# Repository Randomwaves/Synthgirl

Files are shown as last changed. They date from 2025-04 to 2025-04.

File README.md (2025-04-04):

# Synthgirl

Welcome to the official GitHub repository for **Synthgirl** by [Randomwaves](https://randomwaves.io).  
Here you'll find everything you need to explore, modify, or build your own Synthgirl— from firmware to circuit design.

## 📁 Repository Structure

- **hardware/**  
  Schematics, PCB design files, and everything related to the physical build of Synthgirl.

- **software/**  
  Source code for the Synthgirl firmware, libraries, and tools.

## 🛠️ For Developers & Hackers

Whether you're here to flash custom firmware or fork the design, we've made the files open and accessible. Contributions, forks, and pull requests are always welcome.

## 📄 License

All contents of this repository are licensed under the [MIT License](LICENSE).

---

Made with ❤️ by Randomwaves.

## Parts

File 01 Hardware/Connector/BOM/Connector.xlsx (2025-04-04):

Connector
Qty | Value | Device | Package | Parts | Description
1 |  | M20-7910642R | M20-7910642R | JP1
1 | HFW6R-6STE1H1LF | HFW6R-6STE1H1LF | HFW6R-6STE1H1LF | U$1

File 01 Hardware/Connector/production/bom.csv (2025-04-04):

Designator | Footprint | Quantity | Value | LCSC Part #
JP1 | 1X06-SMD-FEMALE-V2 | 1 | M06SMD-FEMALE-V2
U$1 | HFW6R-2STE1LF | 1 | HFW6R-2STE1LF

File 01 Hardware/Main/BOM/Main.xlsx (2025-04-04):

Main
Qty | Value | Device | Package | Parts | Description | ARROW_PART_NUMBER | ARROW_PRICE-STOCK | DESCRIPTION | HEIGHT | MANUFACTURER_NAME | MANUFACTURER_PART_NUMBER | MOUSER_PART_NUMBER | MOUSER_PRICE-STOCK | PROD_ID | VALUE
1 | 68712014022 | 68712014022 | 68712014022 | J4 | Wurth Elektronik 687 Series 0.5mm 20 Way 1 Row Straight PCB Socket Surface Mount Wire to Board |  |  | Wurth Elektronik 687 Series 0.5mm 20 Way 1 Row Straight PCB Socket Surface Mount Wire to Board | 2.1mm | Wurth Elektronik | 68712014022 | 710-68712014022 | https://www.mouser.co.uk/ProductDetail/Wurth-Elektronik/68712014022?qs=ZtY9WdtwX57%2F0bEhtjzEjA%3D%3D
1 | 150060RS75000 | 150060RS75000 | LEDC1608X80N | LED1 | WURTH ELEKTRONIK - 150060RS75000 - LED, 0603, RED, 250MCD, 625NM |  |  | WURTH ELEKTRONIK - 150060RS75000 - LED, 0603, RED, 250MCD, 625NM | 0.8mm | Wurth Elektronik | 150060RS75000 | 710-150060RS75000 | https://www.mouser.co.uk/ProductDetail/Wurth-Elektronik/150060RS75000?qs=LlUlMxKIyB3QnmZ3fw%2FVCA%3D%3D
1 | 150060VS75000 | 150060VS75000 | LEDC1608X80N | LED3 | 2.4 V Green LED 1608 (0603) SMD, Wurth Elektronik WL-SMCW 150060VS75000 |  |  | 2.4 V Green LED 1608 (0603) SMD, Wurth Elektronik WL-SMCW 150060VS75000 | 0.8mm | Wurth Elektronik | 150060VS75000 | 710-150060VS75000 | https://www.mouser.co.uk/ProductDetail/Wurth-Elektronik/150060VS75000?qs=LlUlMxKIyB1Q1Bi5mQ%2FKLw%3D%3D
1 | 150060YS75000 | 150060YS75000 | LEDC1608X80N | LED2 | LED,Wurth Elektronik,150060YS75000 Wurth Elektronik 150060YS75000, WL-SMCW Series Yellow LED, 590 nm, 1608 (0603) Clear, Rectangle Lens SMD Package |  |  | LED,Wurth Elektronik,150060YS75000 Wurth Elektronik 150060YS75000, WL-SMCW Series Yellow LED, 590 nm, 1608 (0603) Clear, Rectangle Lens SMD Package | 0.8mm | Wurth Elektronik | 150060YS75000 | 710-150060YS75000 | https://www.mouser.co.uk/ProductDetail/Wurth-Elektronik/150060YS75000?qs=LlUlMxKIyB0nKmwefHgtZw%3D%3D
1 | 216990-0001 | 216990-0001 | 2169900001 | USB1 | MOLEX - 216990-0001 - USB Connector, USB Type C, USB 2.0, Receptacle, 16 Ways, Surface Mount, Right Angle{0000} |  |  | MOLEX - 216990-0001 - USB Connector, USB Type C, USB 2.0, Receptacle, 16 Ways, Surface Mount, Right Angle{0000} | 3.36mm | Molex | 216990-0001 | 538-216990-0001 | https://www.mouser.co.uk/ProductDetail/Molex/216990-0001?qs=DRkmTr78QAS%252B9wQ3YlpV3Q%3D%3D
1 | 68715014022 | 68715014022 | 68715014022 | J1 | Connector 0.5mm, FFC/FPC, SMT,r/a,50w,FFC/FPC SMT Series 0.5mm Pitch 50 Way Right Angle SMT Female FPC Connector, ZIF Top Contact |  |  | Connector 0.5mm, FFC/FPC, SMT,r/a,50w,FFC/FPC SMT Series 0.5mm Pitch 50 Way Right Angle SMT Female FPC Connector, ZIF Top Contact | 2mm | Wurth Elektronik
1 | ABM7-8.000MHZ-D2Y-T | ABM7-8.000MHZ-D2Y-T | ABM78000MHZD2YT | Y1 | ABRACON - ABM7-8.000MHZ-D2Y-T - CRYSTAL, 8MHZ, 18PF, SMD | ABM7-8.000MHZ-D2Y-T | https://www.arrow.com/en/products/abm7-8.000mhz-d2y-t/abracon | ABRACON - ABM7-8.000MHZ-D2Y-T - CRYSTAL, 8MHZ, 18PF, SMD | 1.4mm | ABRACON | ABM7-8.000MHZ-D2Y-T | 815-ABM7-8-D2Y-T | https://www.mouser.co.uk/ProductDetail/ABRACON/ABM7-8000MHZ-D2Y-T?qs=LoTOQoUkC8SFsmY8snleBA%3D%3D
1 | AP7365-18WG-7 | AP7365-18WG-7 | SOT95P285X130-5N | IC6 | DiodesZetex AP7365-18WG-7, LDO Voltage Regulator, 600mA, 1.8 V +/-2%, 2 6 Vin, 5-Pin SOT-25 | AP7365-33WG-7 | https://www.arrow.com/en/products/ap7365-33wg-7/diodes-incorporated | DiodesZetex AP7365-33WG-7, LDO Voltage Regulator, 600mA, 3.3 V +/-2%, 2 6 Vin, 5-Pin SOT-25 | 1.3mm | Diodes Inc. | AP7365-33WG-7 | 621-AP7365-33WG-7 | https://www.mouser.co.uk/ProductDetail/Diodes-Incorporated/AP7365-33WG-7?qs=abZ1nkZpTuOZFvxvoFPL0w%3D%3D
2 | AP7365-33WG-7 | AP7365-33WG-7 | SOT95P285X130-5N | IC5, IC7 | DiodesZetex AP7365-33WG-7, LDO Voltage Regulator, 600mA, 3.3 V +/-2%, 2 6 Vin, 5-Pin SOT-25 | AP7365-33WG-7 | https://www.arrow.com/en/products/ap7365-33wg-7/diodes-incorporated | DiodesZetex AP7365-33WG-7, LDO Voltage Regulator, 600mA, 3.3 V +/-2%, 2 6 Vin, 5-Pin SOT-25 | 1.3mm | Diodes Inc. | AP7365-33WG-7 | 621-AP7365-33WG-7 | https://www.mouser.co.uk/ProductDetail/Diodes-Incorporated/AP7365-33WG-7?qs=abZ1nkZpTuOZFvxvoFPL0w%3D%3D
32 | 0.1uF | CAP-0603 | CAP-0603 | C1, C2, C3, C4, C5, C6, C7, C9, C11, C12, C13, C14, C15, C21, C24, C25, C26, C27, C28, C29, C30, C31, C33, C34, C35, C36, C38, C39, C41, C43, C45, C46
1 | 10uF | CAP-0603 | CAP-0603 | C19
2 | 1uF | CAP-0603 | CAP-0603 | C20, C22
6 | 2.2uF | CAP-0603 | CAP-0603 | C17, C18, C37, C40, C42, C44
2 | 33pF | CAP-0603 | CAP-0603 | C8, C10
4 | 4.7uF | CAP-0603 | CAP-0603 | C16, C23, C32, C47
2 | 10uF | CAP-POL-1206 | CAP-POL-1206 | CP1, CP2
1 | 1N4148 | DIODESOD-323 | SOD-323 | D2 | Diode
1 | H11L1SM | H11L1SM | SMT-6PIN-(LEAD-BEND) | IC8 | 6-Pin DIP Schmitt Trigger Output Optocoupler |  |  | 6-Pin DIP Schmitt Trigger Output Optocoupler | mm | onsemi | H11L1SM | 512-H11L1SM | https://www.mouser.co.uk/ProductDetail/onsemi-Fairchild/H11L1SM?qs=9h%252BT%2FFFCxR8rbqOmNiGmNQ%3D%3D
1 | HFW6R-1STE1LF | HFW6R-1STE1LF | HFW6R-1STE1LF | J7
1 | IS42S16800F-7TLI | IS42S16800F-7TLI | SOP80P1176X120-54N | IC3 | DRAM 128M, 3.3V, SDRAM, 8Mx16, 143Mhz, 54 pin TSOP II (400 mil) RoHS, IT | IS42S16800F-7TLI | https://www.arrow.com/en/products/is42s16800f-7tli/integrated-silicon-solution-inc | DRAM 128M, 3.3V, SDRAM, 8Mx16, 143Mhz, 54 pin TSOP II (400 mil) RoHS, IT | 1.2mm | Integrated Silicon Solution Inc. | IS42S16800F-7TLI | 870-IS42S16800F-7TLI | https://www.mouser.co.uk/ProductDetail/ISSI/IS42S16800F-7TLI?qs=DfG0HhEx1UWqxa76yijZ5Q%3D%3D
1 | L-KLS1-TF-003-H1.85-R | L-KLS1-TF-003-H1.85-R | L-KLS1-TF-003-H1.85-R | J2 | Micro SD Card Connector |  |  | Micro SD Card Connector | mm | KLS Electronic | L-KLS1-TF-003-H1.85-R
1 | MBR0520LT3G | MBR0520LT3G | SOD3716X135N | D1 | ON SEMICONDUCTOR - MBR0520LT3G - RECTIFIER, SCHOTTKY, 0.5A, 20V, SOD-123 | MBR0520LT3G | https://www.arrow.com/en/products/mbr0520lt3g/on-semiconductor | ON SEMICONDUCTOR - MBR0520LT3G - RECTIFIER, SCHOTTKY, 0.5A, 20V, SOD-123 | 1.35mm | ON Semiconductor | MBR0520LT3G | 863-MBR0520LT3G | https://www.mouser.co.uk/ProductDetail/ON-Semiconductor/MBR0520LT3G?qs=3JMERSakebrHITezQJBmeQ%3D%3D
1 | MP3302DJ-LF-Z | MP3302DJ-LF-Z | SOT95P280X100-5N | IC2 | LED Lighting Drivers 1.3A, 1.3MHz WLED Driver |  |  | LED Lighting Drivers 1.3A, 1.3MHz WLED Driver | 1mm | Monolithic Power Systems (MPS) | MP3302DJ-LF-Z | 946-MP3302DJLFZ | https://www.mouser.co.uk/ProductDetail/Monolithic-Power-Systems-MPS/MP3302DJ-LF-Z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
1 | NRS5024T4R7MMGJ | NRS5024T4R7MMGJ | NRS5024T4R7MMGJ | L1 | Inductor Power Shielded Wirewound 4.7uH 20% 100KHz Ferrite 2A 0.066Ohm DCR T/R | NRS5024T4R7MMGJ | https://www.arrow.com/en/products/nrs5024t4r7mmgj/taiyo-yuden | Inductor Power Shielded Wirewound 4.7uH 20% 100KHz Ferrite 2A 0.066Ohm DCR T/R | 2.4mm | TAIYO YUDEN | NRS5024T4R7MMGJ | 963-NRS5024T4R7MMGJ | https://www.mouser.co.uk/ProductDetail/Taiyo-Yuden/NRS5024T4R7MMGJ?qs=vF%252B8ahGVilffmVxWIbH5HQ%3D%3D
4 | 0 | RES-0603 | RES-0603 | R20, R21, R25, R26
2 | 10 | RES-0603 | RES-0603 | R8, R11
1 | 100 | RES-0603 | RES-0603 | R22
1 | 100K | RES-0603 | RES-0603 | R10
5 | 10K | RES-0603 | RES-0603 | R2, R3, R4, R9, R23
2 | 2.2K | RES-0603 | RES-0603 | R18, R19
6 | 220 | RES-0603 | RES-0603 | R1, R5, R6, R7, R15, R28
2 | 47 | RES-0603 | RES-0603 | R24, R27
1 | 470 | RES-0603 | RES-0603 | R29
5 | 47K | RES-0603 | RES-0603 | R12, R13, R14, R16, R17
3 | 600 | BLM18AG601SN1D | BLM18AG601SN1D | FB01, FB02, FB03
1 | SGTL5000XNAA3 | SGTL5000XNAA3 | QFN50P500X500X90-33N | IC4 | NXP, Audio Codec Stereo Audio 2-channel 24bit- 96kHz Serial-I2C, Serial-SPI 32-Pin QFN | SGTL5000XNAA3 | https://www.arrow.com/en/products/sgtl5000xnaa3/nxp-semiconductors | NXP, Audio Codec Stereo Audio 2-channel 24bit- 96kHz Serial-I2C, Serial-SPI 32-Pin QFN | 0.9mm | NXP | SGTL5000XNAA3 | 841-SGTL5000XNAA3 | https://www.mouser.co.uk/ProductDetail/NXP-Semiconductors/SGTL5000XNAA3?qs=g5o6z0NmdpQ52bnp6yi7dA%3D%3D
5 | SJ-3503-SMT-TR | SJ-3503-SMT-TR | SJ3503SMTTR | J3, J5, J6, J8, J9 | CONN JACK STEREO 3.5MM SMD R/A | SJ-3503-SMT-TR | https://www.arrow.com/en/products/sj-3503-smt-tr/cui-devices?region=nac | CONN JACK STEREO 3.5MM SMD R/A | 5.8mm | CUI Inc. | SJ-3503-SMT-TR | 490-SJ-3503-SMT-TR | https://www.mouser.co.uk/ProductDetail/CUI-Devices/SJ-3503-SMT-TR?qs=WyjlAZoYn52oLXthlnPPpw%3D%3D
1 | STM32H723ZGT6 | STM32H723ZGT6 | QFP50P2200X2200X160-144N | IC1 | ARM Microcontrollers - MCU 16/32-BITS MICROS | STM32H730ZBT6 | https://www.arrow.com/en/products/stm32h730zbt6/stmicroelectronics | ARM Microcontrollers - MCU 16/32-BITS MICROS | 1.6mm | STMicroelectronics | STM32H730ZBT6 | 511-STM32H730ZBT6 | https://www.mouser.co.uk/ProductDetail/STMicroelectronics/STM32H730ZBT6?qs=sPbYRqrBIVmvhxoKLsCUVw%3D%3D
1 | BUTTON | TAC_SWITCHSMD | TS-1187A-B-A-B | S2 | Momentary Switch |  |  |  |  |  |  |  |  | SWCH-08247 | TAC_SWITCHSMD
1 | RST | TAC_SWITCHSMD | TS-1187A-B-A-B | S1 | Momentary Switch |  |  |  |  |  |  |  |  | SWCH-08247 | TAC_SWITCHSMD

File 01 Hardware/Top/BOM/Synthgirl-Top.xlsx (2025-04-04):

Synthgirl-Top
Qty | Value | Device | Package | Parts | Description | ARROW_PART_NUMBER | ARROW_PRICE-STOCK | DESCRIPTION | HEIGHT | MANUFACTURER_NAME | MANUFACTURER_PART_NUMBER | MOUSER_PART_NUMBER | MOUSER_PRICE-STOCK
3 | 0.1uF | CAP-0603 | CAP-0603 | C7, C15, C23
9 | 1M | RES-0603 | RES-0603 | R1, R2, R3, R4, R5, R6, R7, R8, R9
3 | 4.7uF | CAP-0603 | CAP-0603 | C8, C16, C24
18 | 47pF | CAP-0603 | CAP-0603 | C1, C2, C3, C4, C5, C6, C9, C10, C11, C12, C13, C14, C17, C18, C19, C20, C21, C22
1 | 68712014022 | 68712014022 | 68712014022 | J1 | Wurth Elektronik 687 Series 0.5mm 20 Way 1 Row Straight PCB Socket Surface Mount Wire to Board |  |  | Wurth Elektronik 687 Series 0.5mm 20 Way 1 Row Straight PCB Socket Surface Mount Wire to Board | 2.1mm | Wurth Elektronik | 68712014022 | 710-68712014022 | https://www.mouser.co.uk/ProductDetail/Wurth-Elektronik/68712014022?qs=ZtY9WdtwX57%2F0bEhtjzEjA%3D%3D
3 | TTP229-BSF | TTP229-BSF | SOP64P600X175-28N | IC1, IC2, IC3 | TOUCH PAD DETECTOR IC |  |  | TOUCH PAD DETECTOR IC | 1.75mm | TONTEK | TTP229-BSF

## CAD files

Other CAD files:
01 Hardware/Drawing.3dm

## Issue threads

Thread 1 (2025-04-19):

Synthgirl (and probably drumboy) doesn't respect NoteOn Velocity=0

yoctopidg3, 2025-04-19:
Some midi devices (Novation Launchkey mini mk3 for example) send a NoteOn Velocity=0 as their NoteOff. Synthgirl doesn't seem to respect this as a NoteOff which causes the note to just hang. I need to grab an STLink and set up the dev env to test this, but my guess is the fix for it is something like https://github.com/yoctopidg3/Synthgirl/commit/367ab6b85131ef2a65a9eede1acb2ea0eef0c613.

My guess is also that drumboy has the same issue.

yoctopidg3, 2025-04-28:
Opened PRs:

https://github.com/Randomwaves/Synthgirl/pull/2
https://github.com/Randomwaves/Drumboy/pull/1

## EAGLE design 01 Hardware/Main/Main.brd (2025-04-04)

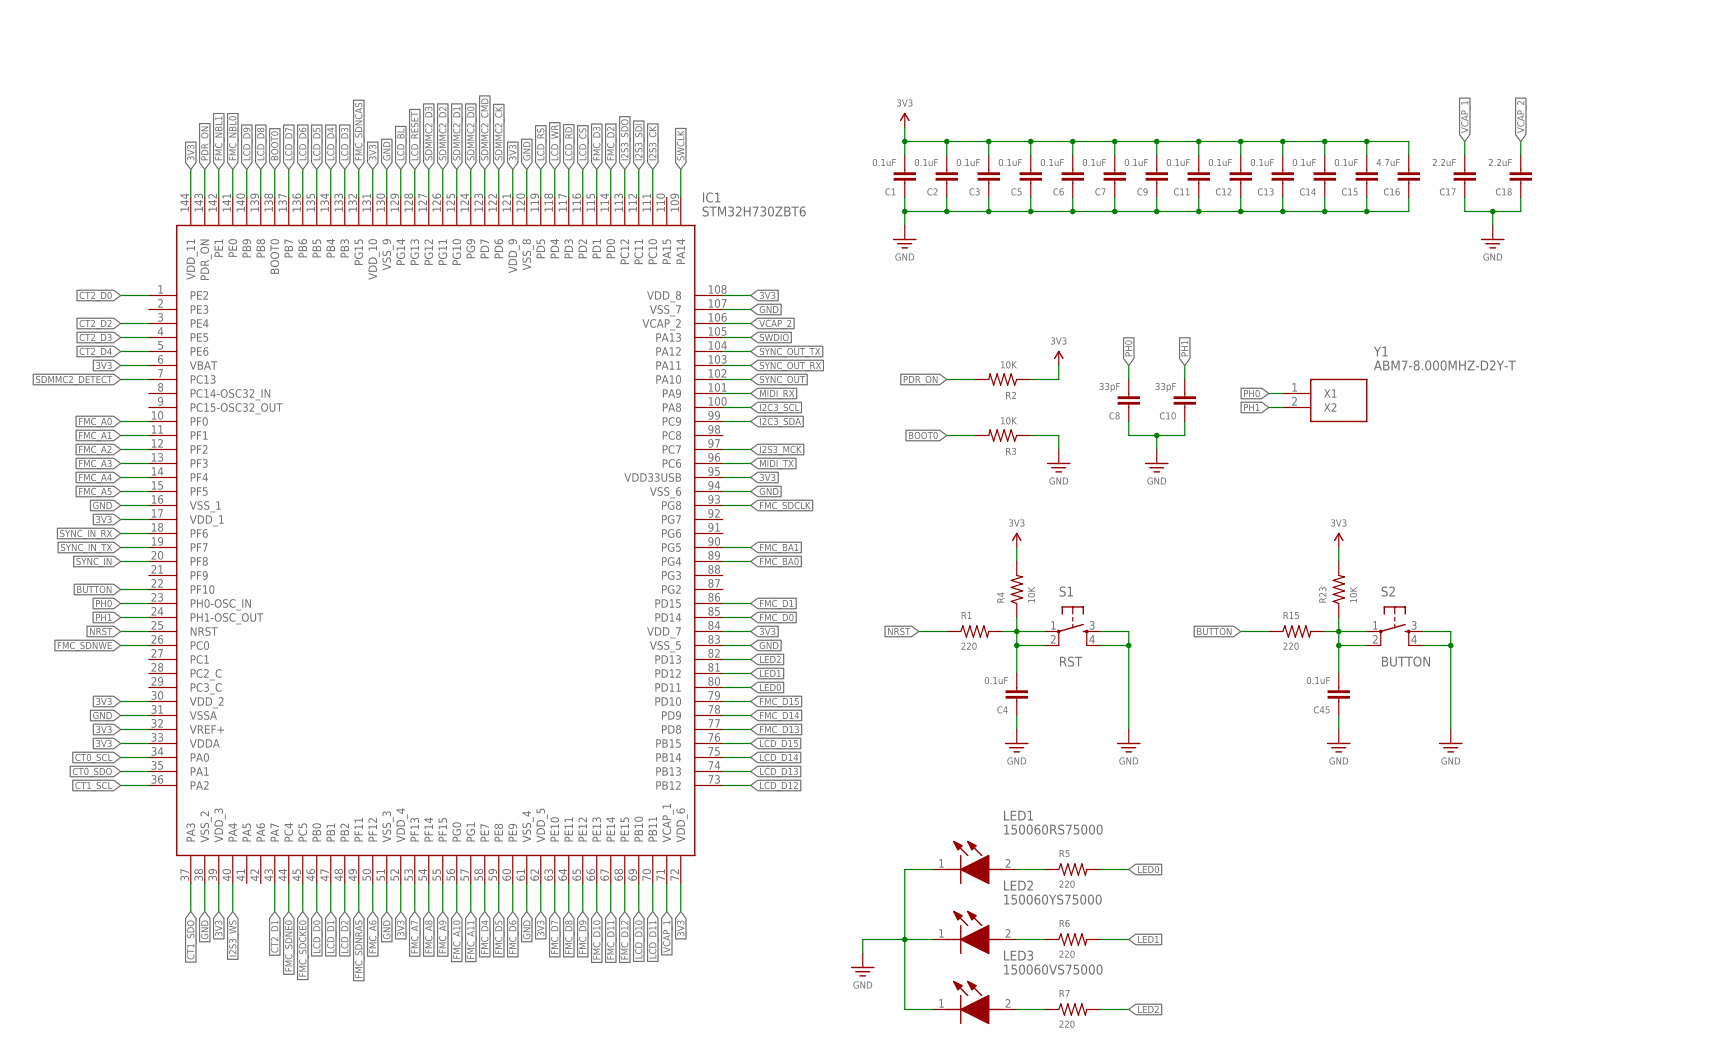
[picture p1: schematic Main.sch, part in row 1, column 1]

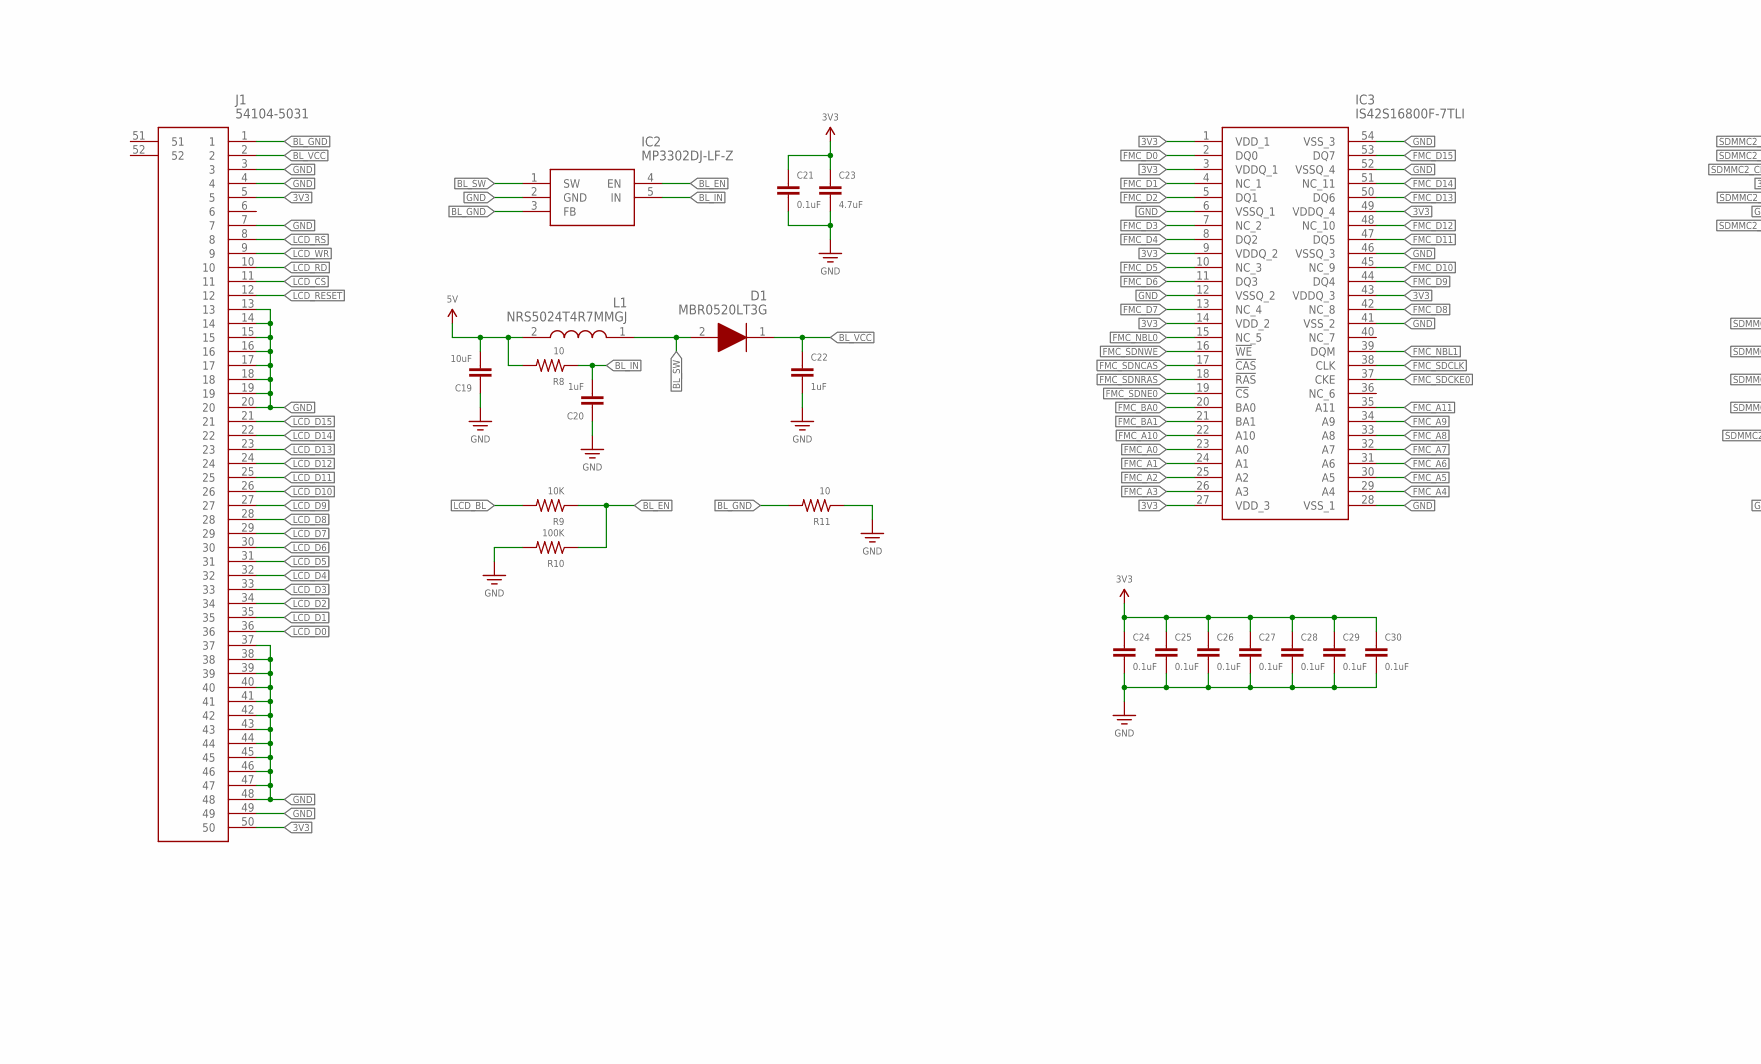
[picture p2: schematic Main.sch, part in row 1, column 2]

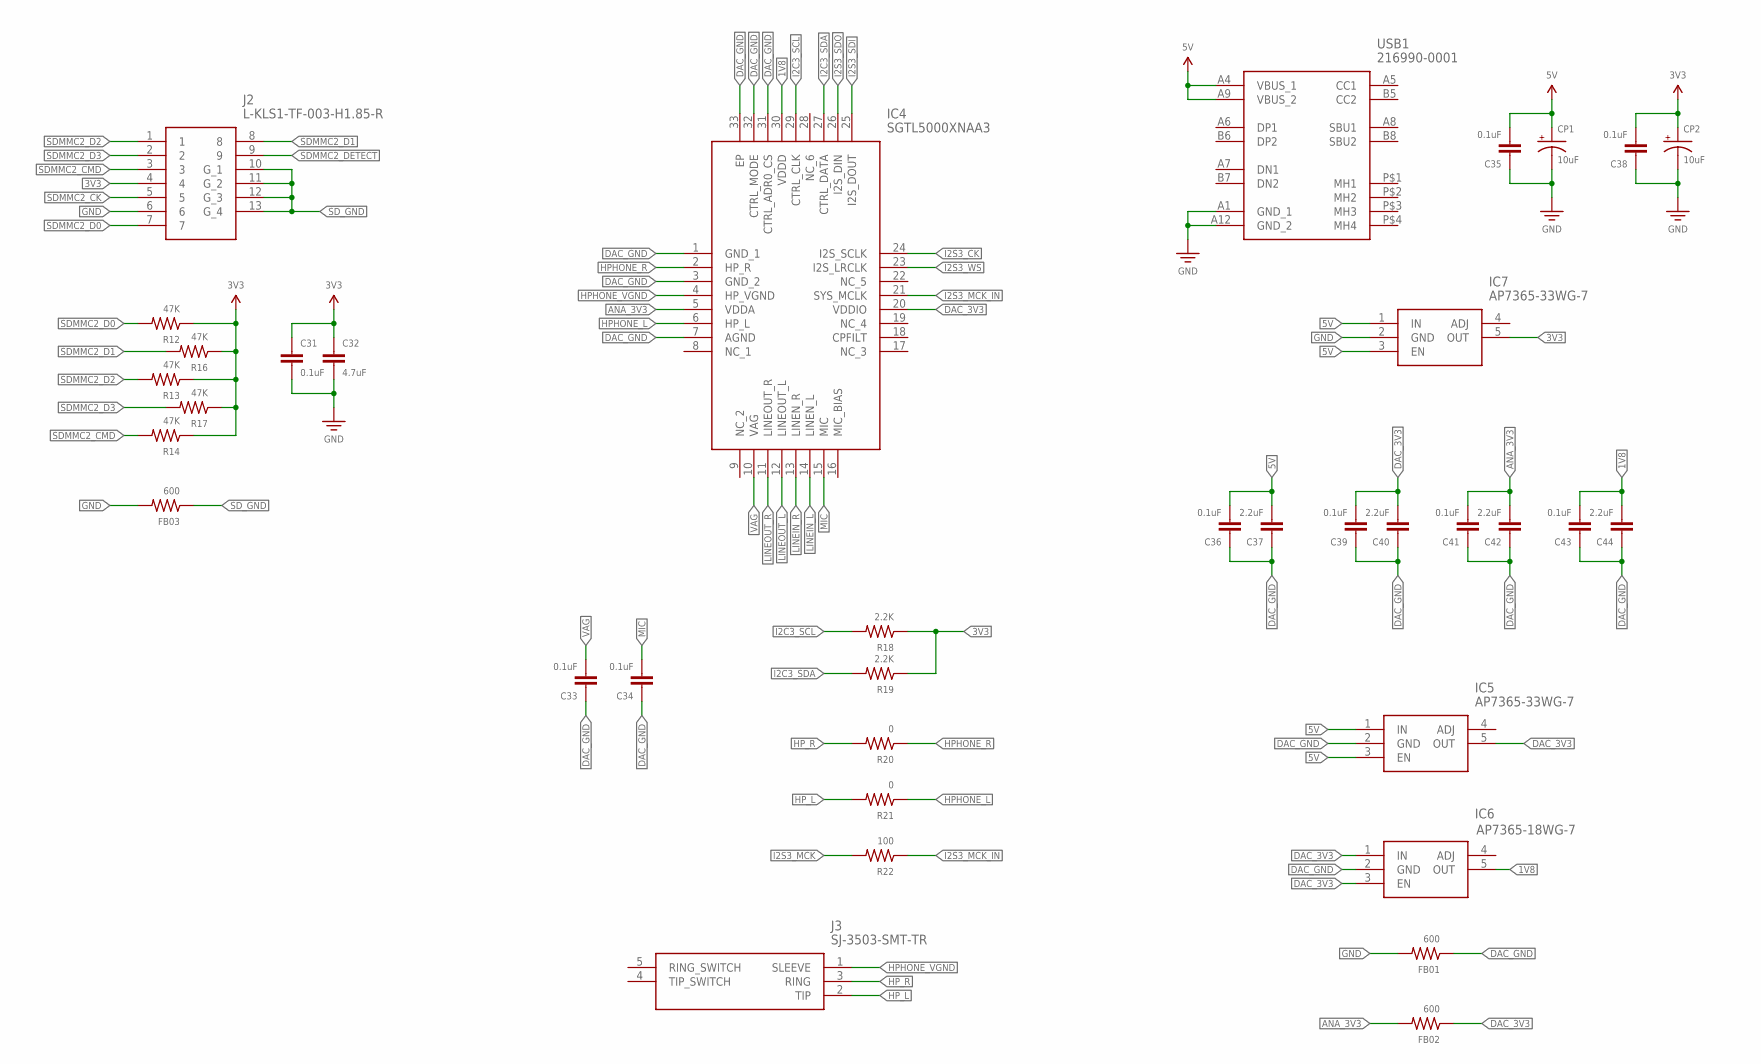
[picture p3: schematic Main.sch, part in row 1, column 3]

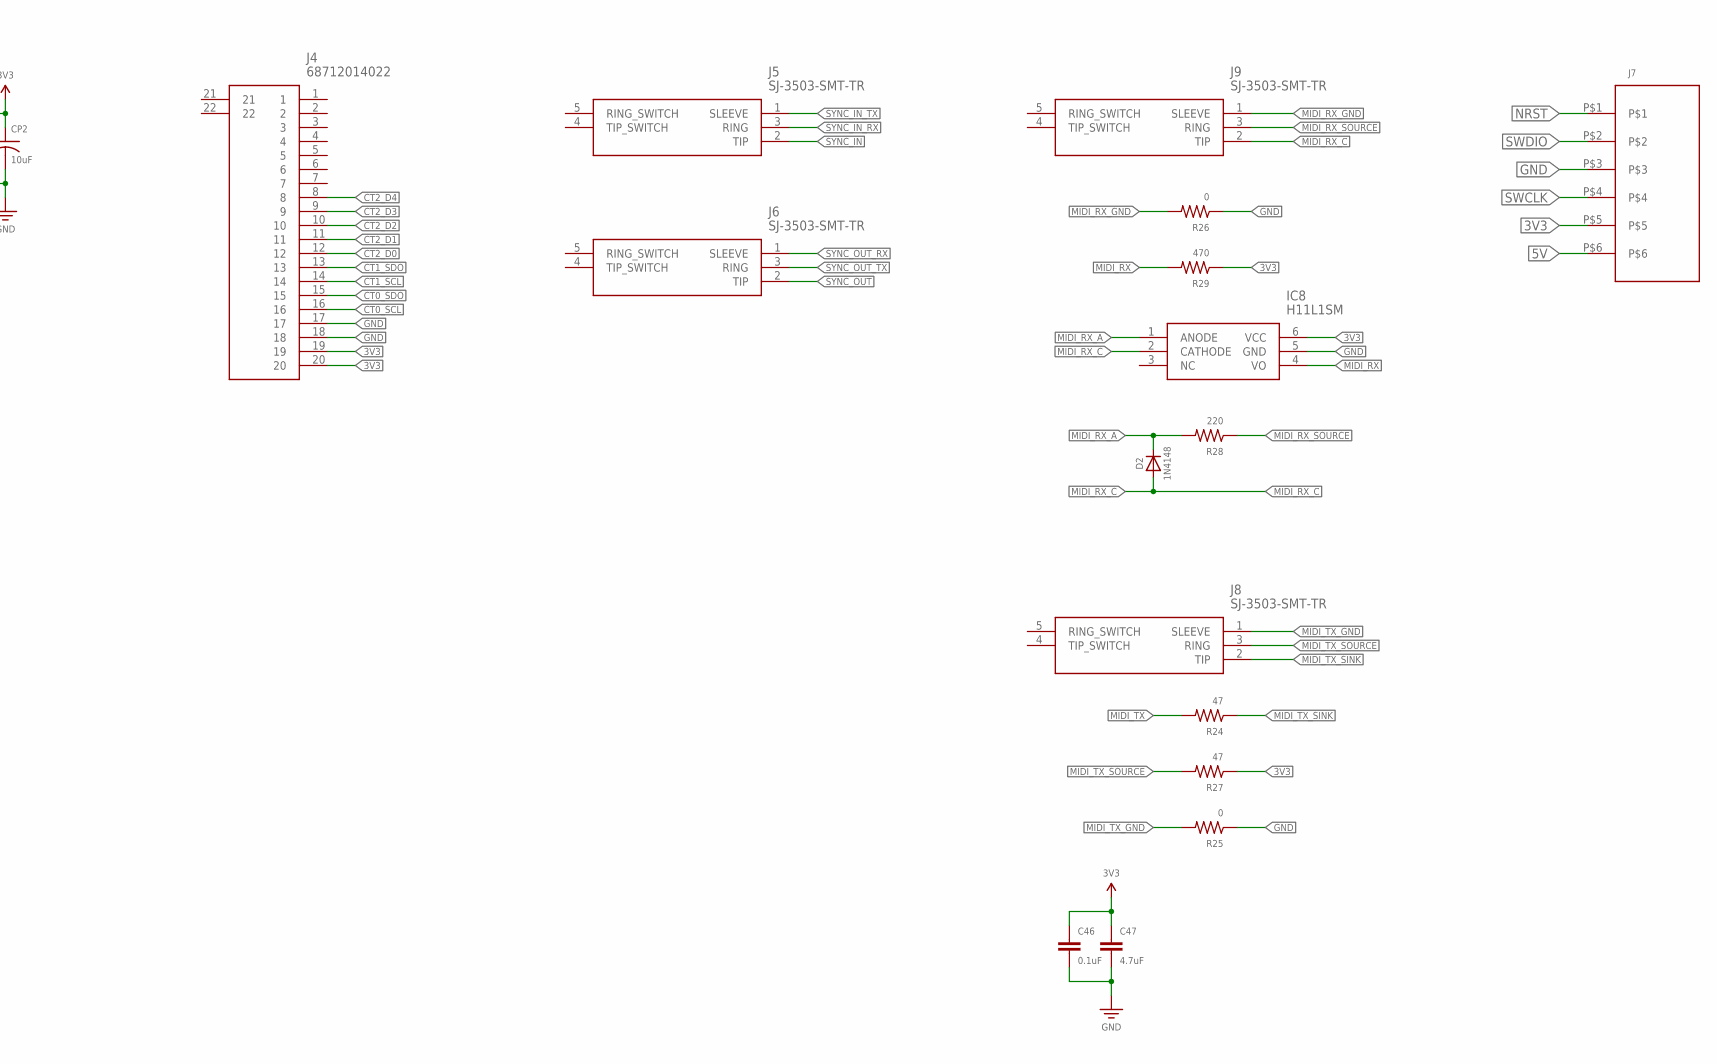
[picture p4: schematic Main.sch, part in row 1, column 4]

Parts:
C1, C2, C3, C4, C5, C6, C7, C9, C11, C12, C13, C14, C15, C21, C24, C25, C26, C27, C28, C29, C30, C31, C33, C34, C35, C36, C38, C39, C41, C43, C45, C46: 0.1uF; CAP-0603
C8, C10: 33pF; CAP-0603
C16, C23, C32, C47: 4.7uF; CAP-0603
C17, C18, C37, C40, C42, C44: 2.2uF; CAP-0603
C19: 10uF; CAP-0603
C20, C22: 1uF; CAP-0603
CP1, CP2: 10uF; CAP-POL-1206
D1: MBR0520LT3G; SOD3716X135N
D2: 1N4148; SOD-323
FB01, FB02, FB03: 600; RES-0603
IC1: STM32H730ZBT6; QFP50P2200X2200X160-144N
IC2: MP3302DJ-LF-Z; SOT95P280X100-5N
IC3: IS42S16800F-7TLI; SOP80P1176X120-54N
IC4: SGTL5000XNAA3; QFN50P500X500X90-33N
IC5, IC7: AP7365-33WG-7; SOT95P285X130-5N
IC6: AP7365-18WG-7; SOT95P285X130-5N
IC8: H11L1SM; SMT-6PIN-(LEAD-BEND)
J1: 54104-5031; 541045031
J2: L-KLS1-TF-003-H1.85-R
J3, J5, J6, J8, J9: SJ-3503-SMT-TR; SJ3503SMTTR
J4: 68712014022
J7: HFW6R-2STE1LF
L1: NRS5024T4R7MMGJ
LED1: 150060RS75000; LEDC1608X80N
LED2: 150060YS75000; LEDC1608X80N
LED3: 150060VS75000; LEDC1608X80N
R1, R5, R6, R7, R15, R28: 220; RES-0603
R2, R3, R4, R9, R23: 10K; RES-0603
R8, R11: 10; RES-0603
R10: 100K; RES-0603
R12, R13, R14, R16, R17: 47K; RES-0603
R18, R19: 2.2K; RES-0603
R20, R21, R25, R26: 0; RES-0603
R22: 100; RES-0603
R24, R27: 47; RES-0603
R29: 470; RES-0603
S1: RST; TACTILE-SWITCH-SMD
S2: BUTTON; TACTILE-SWITCH-SMD
USB1: 216990-0001; 2169900001
Y1: ABM7-8.000MHZ-D2Y-T; ABM78000MHZD2YT

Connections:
1V8: C43.P$2 (2), C44.P$2 (2), IC4.30 (VDDD), IC6.5 (OUT)
3V3: C1.P$2 (2), C2.P$2 (2), C3.P$2 (2), C5.P$2 (2), C6.P$2 (2), C7.P$2 (2), C9.P$2 (2), C11.P$2 (2), C12.P$2 (2), C13.P$2 (2), C14.P$2 (2), C15.P$2 (2), C16.P$2 (2), C21.P$1 (1), C23.P$1 (1), C24.P$1 (1), C25.P$1 (1), C26.P$1 (1), C27.P$1 (1), C28.P$1 (1), C29.P$1 (1), C30.P$1 (1), C31.P$1 (1), C32.P$1 (1), C38.P$2 (2), C46.P$1 (1), C47.P$1 (1), CP2.P$1 (+), IC1.6 (VBAT), IC1.17 (VDD_1), IC1.30 (VDD_2), IC1.32 (VREF+), IC1.33 (VDDA), IC1.39 (VDD_3), IC1.52 (VDD_4), IC1.62 (VDD_5), IC1.72 (VDD_6), IC1.84 (VDD_7), IC1.95 (VDD33USB), IC1.108 (VDD_8), IC1.121 (VDD_9), IC1.131 (VDD_10), IC1.144 (VDD_11), IC3.1 (VDD_1), IC3.3 (VDDQ_1), IC3.9 (VDDQ_2), IC3.14 (VDD_2), IC3.27 (VDD_3), IC3.43 (VDDQ_3), IC3.49 (VDDQ_4), IC7.5 (OUT), IC8.6 (VCC), J1.5, J1.50, J2.4, J4.19, J4.20, J7.P$5, R2.P$1 (1), R4.P$2 (2), R12.P$1 (1), R13.P$1 (1), R14.P$1 (1), R16.P$1 (1), R17.P$1 (1), R18.P$1 (1), R19.P$1 (1), R23.P$2 (2), R27.P$1 (1), R29.P$1 (1)
5V: C19.P$2 (2), C35.P$2 (2), C36.P$2 (2), C37.P$2 (2), CP1.P$1 (+), IC5.1 (IN), IC5.3 (EN), IC7.1 (IN), IC7.3 (EN), J7.P$6, L1.2, R8.P$2 (2), USB1.A4 (VBUS_1), USB1.A9 (VBUS_2)
ANA_3V3: C41.P$2 (2), C42.P$2 (2), FB02.P$2 (2), IC4.5 (VDDA)
BL_EN: IC2.4 (EN), R9.P$1 (1), R10.P$1 (1)
BL_GND: IC2.3 (FB), J1.1, R11.P$2 (2)
BL_IN: C20.P$2 (2), IC2.5 (IN), R8.P$1 (1)
BL_SW: D1.2 (A), IC2.1 (SW), L1.1
BL_VCC: C22.P$1 (1), D1.1 (K), J1.2
BOOT0: IC1.138 (BOOT0), R3.P$2 (2)
BUTTON: IC1.22 (PF10), R15.P$1 (1)
CT0_SCL: IC1.34 (PA0), J4.16
CT0_SDO: IC1.35 (PA1), J4.15
CT1_SCL: IC1.36 (PA2), J4.14
CT1_SDO: IC1.37 (PA3), J4.13
CT2_D0: IC1.1 (PE2), J4.12
CT2_D1: IC1.43 (PA7), J4.11
CT2_D2: IC1.3 (PE4), J4.10
CT2_D3: IC1.4 (PE5), J4.9
CT2_D4: IC1.5 (PE6), J4.8
DAC_3V3: C39.P$2 (2), C40.P$2 (2), FB02.P$1 (1), IC4.20 (VDDIO), IC5.5 (OUT), IC6.1 (IN), IC6.3 (EN)
DAC_GND: C33.P$1 (1), C34.P$1 (1), C36.P$1 (1), C37.P$1 (1), C39.P$1 (1), C40.P$1 (1), C41.P$1 (1), C42.P$1 (1), C43.P$1 (1), C44.P$1 (1), FB01.P$1 (1), IC4.1 (GND_1), IC4.3 (GND_2), IC4.7 (AGND), IC4.31 (CTRL_ADR0_CS), IC4.32 (CTRL_MODE), IC4.33 (EP), IC5.2 (GND), IC6.2 (GND)
FMC_A0: IC1.10 (PF0), IC3.23 (A0)
FMC_A1: IC1.11 (PF1), IC3.24 (A1)
FMC_A2: IC1.12 (PF2), IC3.25 (A2)
FMC_A3: IC1.13 (PF3), IC3.26 (A3)
FMC_A4: IC1.14 (PF4), IC3.29 (A4)
FMC_A5: IC1.15 (PF5), IC3.30 (A5)
FMC_A6: IC1.50 (PF12), IC3.31 (A6)
FMC_A7: IC1.53 (PF13), IC3.32 (A7)
FMC_A8: IC1.54 (PF14), IC3.33 (A8)
FMC_A9: IC1.55 (PF15), IC3.34 (A9)
FMC_A10: IC1.56 (PG0), IC3.22 (A10)
FMC_A11: IC1.57 (PG1), IC3.35 (A11)
FMC_BA0: IC1.89 (PG4), IC3.20 (BA0)
FMC_BA1: IC1.90 (PG5), IC3.21 (BA1)
FMC_D0: IC1.85 (PD14), IC3.2 (DQ0)
FMC_D1: IC1.86 (PD15), IC3.4 (NC_1)
FMC_D2: IC1.114 (PD0), IC3.5 (DQ1)
FMC_D3: IC1.115 (PD1), IC3.7 (NC_2)
FMC_D4: IC1.58 (PE7), IC3.8 (DQ2)
FMC_D5: IC1.59 (PE8), IC3.10 (NC_3)
FMC_D6: IC1.60 (PE9), IC3.11 (DQ3)
FMC_D7: IC1.63 (PE10), IC3.13 (NC_4)
FMC_D8: IC1.64 (PE11), IC3.42 (NC_8)
FMC_D9: IC1.65 (PE12), IC3.44 (DQ4)
FMC_D10: IC1.66 (PE13), IC3.45 (NC_9)
FMC_D11: IC1.67 (PE14), IC3.47 (DQ5)
FMC_D12: IC1.68 (PE15), IC3.48 (NC_10)
FMC_D13: IC1.77 (PD8), IC3.50 (DQ6)
FMC_D14: IC1.78 (PD9), IC3.51 (NC_11)
FMC_D15: IC1.79 (PD10), IC3.53 (DQ7)
FMC_NBL0: IC1.141 (PE0), IC3.15 (NC_5)
FMC_NBL1: IC1.142 (PE1), IC3.39 (DQM)
FMC_SDCKE0: IC1.45 (PC5), IC3.37 (CKE)
FMC_SDCLK: IC1.93 (PG8), IC3.38 (CLK)
FMC_SDNCAS: IC1.132 (PG15), IC3.17 (!CAS)
FMC_SDNE0: IC1.44 (PC4), IC3.19 (!CS)
FMC_SDNRAS: IC1.49 (PF11), IC3.18 (!RAS)
FMC_SDNWE: IC1.26 (PC0), IC3.16 (!WE)
GND: C1.P$1 (1), C2.P$1 (1), C3.P$1 (1), C4.P$1 (1), C5.P$1 (1), C6.P$1 (1), C7.P$1 (1), C8.P$1 (1), C9.P$1 (1), C10.P$1 (1), C11.P$1 (1), C12.P$1 (1), C13.P$1 (1), C14.P$1 (1), C15.P$1 (1), C16.P$1 (1), C17.P$1 (1), C18.P$1 (1), C19.P$1 (1), C20.P$1 (1), C21.P$2 (2), C22.P$2 (2), C23.P$2 (2), C24.P$2 (2), C25.P$2 (2), C26.P$2 (2), C27.P$2 (2), C28.P$2 (2), C29.P$2 (2), C30.P$2 (2), C31.P$2 (2), C32.P$2 (2), C35.P$1 (1), C38.P$1 (1), C45.P$1 (1), C46.P$2 (2), C47.P$2 (2), CP1.P$2 (-), CP2.P$2 (-), FB01.P$2 (2), FB03.P$2 (2), IC1.16 (VSS_1), IC1.31 (VSSA), IC1.38 (VSS_2), IC1.51 (VSS_3), IC1.61 (VSS_4), IC1.83 (VSS_5), IC1.94 (VSS_6), IC1.107 (VSS_7), IC1.120 (VSS_8), IC1.130 (VSS_9), IC2.2 (GND), IC3.6 (VSSQ_1), IC3.12 (VSSQ_2), IC3.28 (VSS_1), IC3.41 (VSS_2), IC3.46 (VSSQ_3), IC3.52 (VSSQ_4), IC3.54 (VSS_3), IC7.2 (GND), IC8.5 (GND), J1.3, J1.4, J1.7, J1.13, J1.14, J1.15, J1.16, J1.17, J1.18, J1.19, J1.20, J1.37, J1.38, J1.39, J1.40, J1.41, J1.42, J1.43, J1.44, J1.45, J1.46, J1.47, J1.48, J1.49, J2.6, J4.17, J4.18, J7.P$3, LED1.1 (K), LED2.1 (K), LED3.1 (K), R3.P$1 (1), R10.P$2 (2), R11.P$1 (1), R25.P$1 (1), R26.P$1 (1), S1.3, S1.4, S2.3, S2.4, USB1.A1 (GND_1), USB1.A12 (GND_2)
HPHONE_L: IC4.6 (HP_L), R21.P$1 (1)
HPHONE_R: IC4.2 (HP_R), R20.P$1 (1)
HPHONE_VGND: IC4.4 (HP_VGND), J3.1 (SLEEVE)
HP_L: J3.2 (TIP), R21.P$2 (2)
HP_R: J3.3 (RING), R20.P$2 (2)
I2C3_SCL: IC1.100 (PA8), IC4.29 (CTRL_CLK), R18.P$2 (2)
I2C3_SDA: IC1.99 (PC9), IC4.27 (CTRL_DATA), R19.P$2 (2)
I2S3_CK: IC1.111 (PC10), IC4.24 (I2S_SCLK)
I2S3_MCK: IC1.97 (PC7), R22.P$2 (2)
I2S3_MCK_IN: IC4.21 (SYS_MCLK), R22.P$1 (1)
I2S3_SDI: IC1.112 (PC11), IC4.25 (I2S_DOUT)
I2S3_SDO: IC1.113 (PC12), IC4.26 (I2S_DIN)
I2S3_WS: IC1.40 (PA4), IC4.23 (I2S_LRCLK)
LCD_BL: IC1.129 (PG14), R9.P$2 (2)
LCD_CS: IC1.116 (PD2), J1.11
LCD_D0: IC1.46 (PB0), J1.36
LCD_D1: IC1.47 (PB1), J1.35
LCD_D2: IC1.48 (PB2), J1.34
LCD_D3: IC1.133 (PB3), J1.33
LCD_D4: IC1.134 (PB4), J1.32
LCD_D5: IC1.135 (PB5), J1.31
LCD_D6: IC1.136 (PB6), J1.30
LCD_D7: IC1.137 (PB7), J1.29
LCD_D8: IC1.139 (PB8), J1.28
LCD_D9: IC1.140 (PB9), J1.27
LCD_D10: IC1.69 (PB10), J1.26
LCD_D11: IC1.70 (PB11), J1.25
LCD_D12: IC1.73 (PB12), J1.24
LCD_D13: IC1.74 (PB13), J1.23
LCD_D14: IC1.75 (PB14), J1.22
LCD_D15: IC1.76 (PB15), J1.21
LCD_RD: IC1.117 (PD3), J1.10
LCD_RESET: IC1.128 (PG13), J1.12
LCD_RS: IC1.119 (PD5), J1.8
LCD_WR: IC1.118 (PD4), J1.9
LED0: IC1.80 (PD11), R5.P$2 (2)
LED1: IC1.81 (PD12), R6.P$2 (2)
LED2: IC1.82 (PD13), R7.P$2 (2)
LINEIN_L: IC4.14 (LINEN_L)
LINEIN_R: IC4.13 (LINEN_R)
LINEOUT_L: IC4.12 (LINEOUT_L)
LINEOUT_R: IC4.11 (LINEOUT_R)
MIC: C34.P$2 (2), IC4.15 (MIC)
MIDI_RX: IC1.101 (PA9), IC8.4 (VO), R29.P$2 (2)
MIDI_RX_A: D2.C, IC8.1 (ANODE), R28.P$2 (2)
MIDI_RX_C: D2.A, IC8.2 (CATHODE), J9.2 (TIP)
MIDI_RX_GND: J9.1 (SLEEVE), R26.P$2 (2)
MIDI_RX_SOURCE: J9.3 (RING), R28.P$1 (1)
MIDI_TX: IC1.96 (PC6), R24.P$2 (2)
MIDI_TX_GND: J8.1 (SLEEVE), R25.P$2 (2)
MIDI_TX_SINK: J8.2 (TIP), R24.P$1 (1)
MIDI_TX_SOURCE: J8.3 (RING), R27.P$2 (2)
unnamed: C45.P$2 (2), R15.P$2 (2), R23.P$1 (1), S2.1, S2.2
unnamed: C4.P$2 (2), R1.P$2 (2), R4.P$1 (1), S1.1, S1.2
unnamed: LED1.2 (A), R5.P$1 (1)
unnamed: LED2.2 (A), R6.P$1 (1)
unnamed: LED3.2 (A), R7.P$1 (1)
NRST: IC1.25 (NRST), J7.P$1, R1.P$1 (1)
PDR_ON: IC1.143 (PDR_ON), R2.P$2 (2)
PH0: C8.P$2 (2), IC1.23 (PH0-OSC_IN), Y1.1 (X1)
PH1: C10.P$2 (2), IC1.24 (PH1-OSC_OUT), Y1.2 (X2)
SDMMC2_CK: IC1.122 (PD6), J2.5
SDMMC2_CMD: IC1.123 (PD7), J2.3, R14.P$2 (2)
SDMMC2_D0: IC1.124 (PG9), J2.7, R12.P$2 (2)
SDMMC2_D1: IC1.125 (PG10), J2.8, R16.P$2 (2)
SDMMC2_D2: IC1.126 (PG11), J2.1, R13.P$2 (2)
SDMMC2_D3: IC1.127 (PG12), J2.2, R17.P$2 (2)
SDMMC2_DETECT: IC1.7 (PC13), J2.9
SD_GND: FB03.P$1 (1), J2.10 (G_1), J2.11 (G_2), J2.12 (G_3), J2.13 (G_4)
SWCLK: IC1.109 (PA14), J7.P$4
SWDIO: IC1.105 (PA13), J7.P$2
SYNC_IN: IC1.20 (PF8), J5.2 (TIP)
SYNC_IN_RX: IC1.18 (PF6), J5.3 (RING)
SYNC_IN_TX: IC1.19 (PF7), J5.1 (SLEEVE)
SYNC_OUT: IC1.102 (PA10), J6.2 (TIP)
SYNC_OUT_RX: IC1.103 (PA11), J6.1 (SLEEVE)
SYNC_OUT_TX: IC1.104 (PA12), J6.3 (RING)
VAG: C33.P$2 (2), IC4.10 (VAG)
VCAP_1: C17.P$2 (2), IC1.71 (VCAP_1)
VCAP_2: C18.P$2 (2), IC1.106 (VCAP_2)

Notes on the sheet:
AP7365-18WG-7

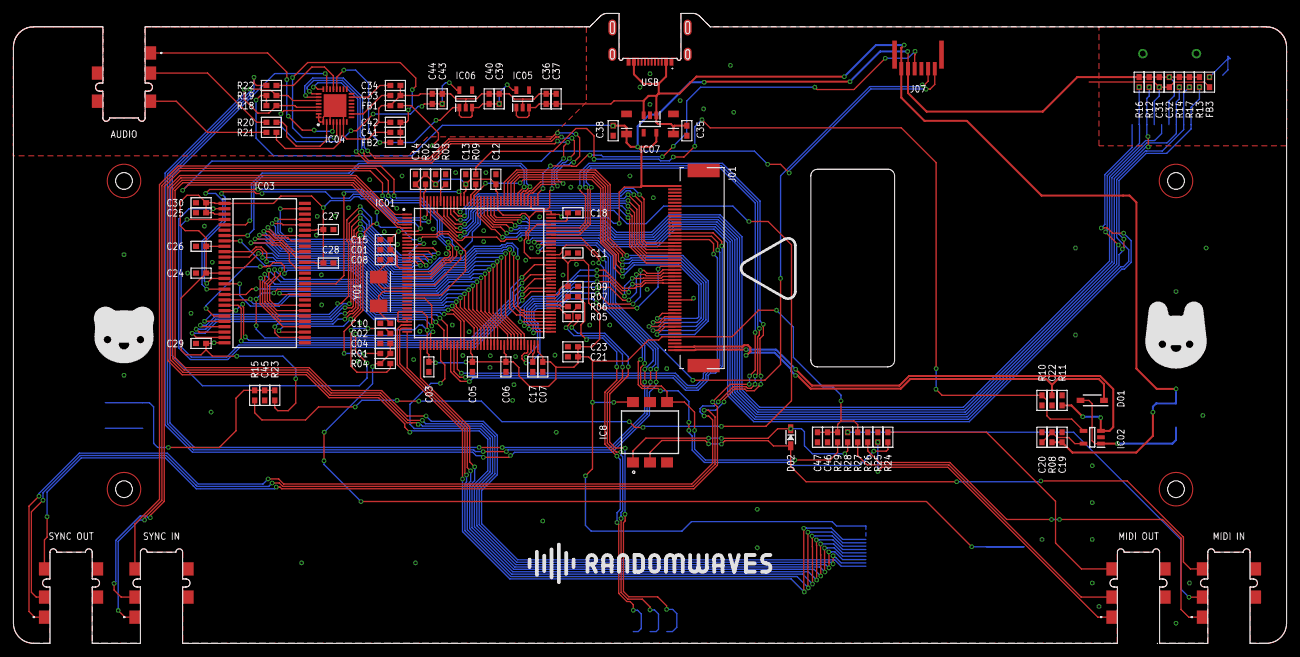
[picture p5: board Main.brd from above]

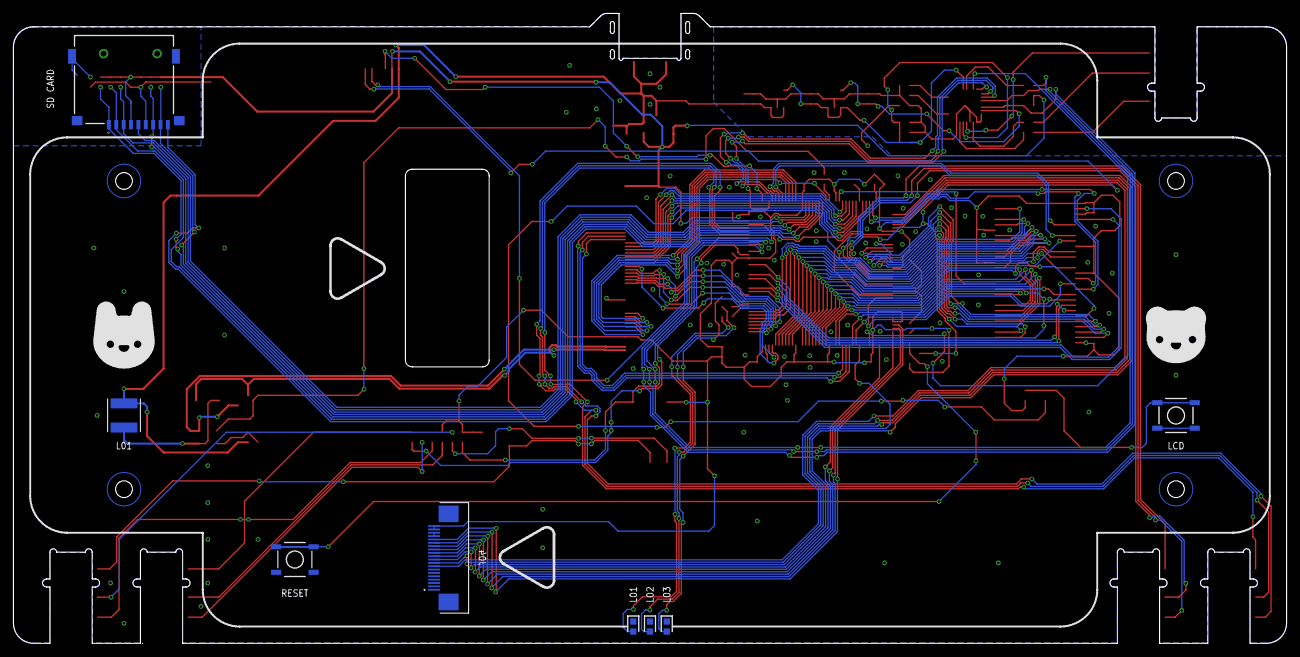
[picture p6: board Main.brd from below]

Board: 2 copper layers, 190.0 x 94.0 mm, 108 parts (8 on the bottom side), 137 nets.

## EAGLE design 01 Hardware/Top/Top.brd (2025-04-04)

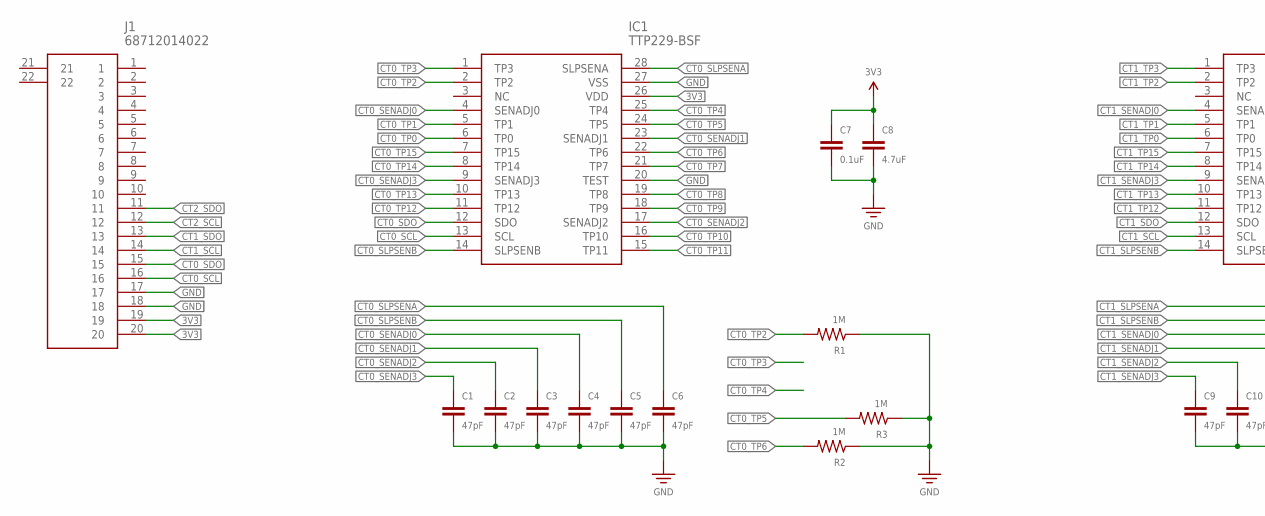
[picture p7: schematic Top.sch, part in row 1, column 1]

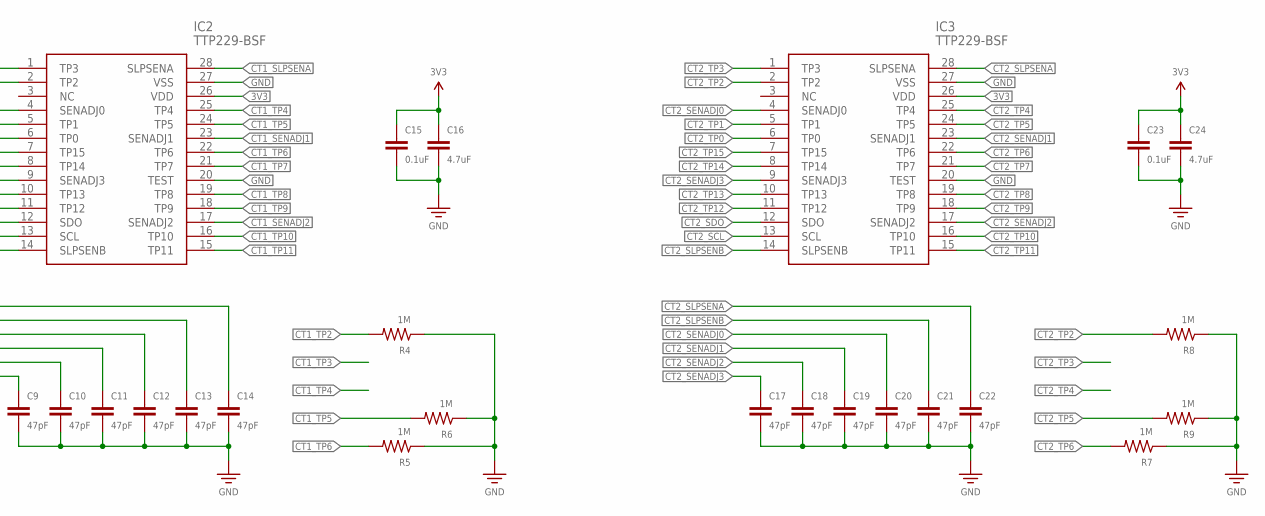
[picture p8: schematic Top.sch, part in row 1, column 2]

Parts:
C1, C2, C3, C4, C5, C6, C9, C10, C11, C12, C13, C14, C17, C18, C19, C20, C21, C22: 47pF; CAP-0603
C7, C15, C23: 0.1uF; CAP-0603
C8, C16, C24: 4.7uF; CAP-0603
IC1, IC2, IC3: TTP229-BSF; SOP64P600X175-28N
J1: 68712014022
R1, R2, R3, R4, R5, R6, R7, R8, R9: 1M; RES-0603

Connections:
3V3: C7.P$1 (1), C8.P$1 (1), C15.P$1 (1), C16.P$1 (1), C23.P$1 (1), C24.P$1 (1), IC1.26 (VDD), IC2.26 (VDD), IC3.26 (VDD), J1.19, J1.20
CT0_SCL: IC1.13 (SCL), J1.16
CT0_SDO: IC1.12 (SDO), J1.15
CT0_SENADJ0: C4.P$1 (1), IC1.4 (SENADJ0)
CT0_SENADJ1: C3.P$1 (1), IC1.23 (SENADJ1)
CT0_SENADJ2: C2.P$1 (1), IC1.17 (SENADJ2)
CT0_SENADJ3: C1.P$1 (1), IC1.9 (SENADJ3)
CT0_SLPSENA: C6.P$1 (1), IC1.28 (SLPSENA)
CT0_SLPSENB: C5.P$1 (1), IC1.14 (SLPSENB)
CT0_TP0: IC1.6 (TP0)
CT0_TP1: IC1.5 (TP1)
CT0_TP2: IC1.2 (TP2), R1.P$2 (2)
CT0_TP3: IC1.1 (TP3)
CT0_TP4: IC1.25 (TP4)
CT0_TP5: IC1.24 (TP5), R3.P$2 (2)
CT0_TP6: IC1.22 (TP6), R2.P$2 (2)
CT0_TP7: IC1.21 (TP7)
CT0_TP8: IC1.19 (TP8)
CT0_TP9: IC1.18 (TP9)
CT0_TP10: IC1.16 (TP10)
CT0_TP11: IC1.15 (TP11)
CT0_TP12: IC1.11 (TP12)
CT0_TP13: IC1.10 (TP13)
CT0_TP14: IC1.8 (TP14)
CT0_TP15: IC1.7 (TP15)
CT1_SCL: IC2.13 (SCL), J1.14
CT1_SDO: IC2.12 (SDO), J1.13
CT1_SENADJ0: C12.P$1 (1), IC2.4 (SENADJ0)
CT1_SENADJ1: C11.P$1 (1), IC2.23 (SENADJ1)
CT1_SENADJ2: C10.P$1 (1), IC2.17 (SENADJ2)
CT1_SENADJ3: C9.P$1 (1), IC2.9 (SENADJ3)
CT1_SLPSENA: C14.P$1 (1), IC2.28 (SLPSENA)
CT1_SLPSENB: C13.P$1 (1), IC2.14 (SLPSENB)
CT1_TP0: IC2.6 (TP0)
CT1_TP1: IC2.5 (TP1)
CT1_TP2: IC2.2 (TP2), R4.P$2 (2)
CT1_TP3: IC2.1 (TP3)
CT1_TP4: IC2.25 (TP4)
CT1_TP5: IC2.24 (TP5), R6.P$2 (2)
CT1_TP6: IC2.22 (TP6), R5.P$2 (2)
CT1_TP7: IC2.21 (TP7)
CT1_TP8: IC2.19 (TP8)
CT1_TP9: IC2.18 (TP9)
CT1_TP10: IC2.16 (TP10)
CT1_TP11: IC2.15 (TP11)
CT1_TP12: IC2.11 (TP12)
CT1_TP13: IC2.10 (TP13)
CT1_TP14: IC2.8 (TP14)
CT1_TP15: IC2.7 (TP15)
CT2_SCL: IC3.13 (SCL), J1.12
CT2_SDO: IC3.12 (SDO), J1.11
CT2_SENADJ0: C20.P$1 (1), IC3.4 (SENADJ0)
CT2_SENADJ1: C19.P$1 (1), IC3.23 (SENADJ1)
CT2_SENADJ2: C18.P$1 (1), IC3.17 (SENADJ2)
CT2_SENADJ3: C17.P$1 (1), IC3.9 (SENADJ3)
CT2_SLPSENA: C22.P$1 (1), IC3.28 (SLPSENA)
CT2_SLPSENB: C21.P$1 (1), IC3.14 (SLPSENB)
CT2_TP0: IC3.6 (TP0)
CT2_TP1: IC3.5 (TP1)
CT2_TP2: IC3.2 (TP2), R8.P$2 (2)
CT2_TP3: IC3.1 (TP3)
CT2_TP4: IC3.25 (TP4)
CT2_TP5: IC3.24 (TP5), R9.P$2 (2)
CT2_TP6: IC3.22 (TP6), R7.P$2 (2)
CT2_TP7: IC3.21 (TP7)
CT2_TP8: IC3.19 (TP8)
CT2_TP9: IC3.18 (TP9)
CT2_TP10: IC3.16 (TP10)
CT2_TP11: IC3.15 (TP11)
CT2_TP12: IC3.11 (TP12)
CT2_TP13: IC3.10 (TP13)
CT2_TP14: IC3.8 (TP14)
CT2_TP15: IC3.7 (TP15)
GND: C1.P$2 (2), C2.P$2 (2), C3.P$2 (2), C4.P$2 (2), C5.P$2 (2), C6.P$2 (2), C7.P$2 (2), C8.P$2 (2), C9.P$2 (2), C10.P$2 (2), C11.P$2 (2), C12.P$2 (2), C13.P$2 (2), C14.P$2 (2), C15.P$2 (2), C16.P$2 (2), C17.P$2 (2), C18.P$2 (2), C19.P$2 (2), C20.P$2 (2), C21.P$2 (2), C22.P$2 (2), C23.P$2 (2), C24.P$2 (2), IC1.20 (TEST), IC1.27 (VSS), IC2.20 (TEST), IC2.27 (VSS), IC3.20 (TEST), IC3.27 (VSS), J1.17, J1.18, R1.P$1 (1), R2.P$1 (1), R3.P$1 (1), R4.P$1 (1), R5.P$1 (1), R6.P$1 (1), R7.P$1 (1), R8.P$1 (1), R9.P$1 (1)

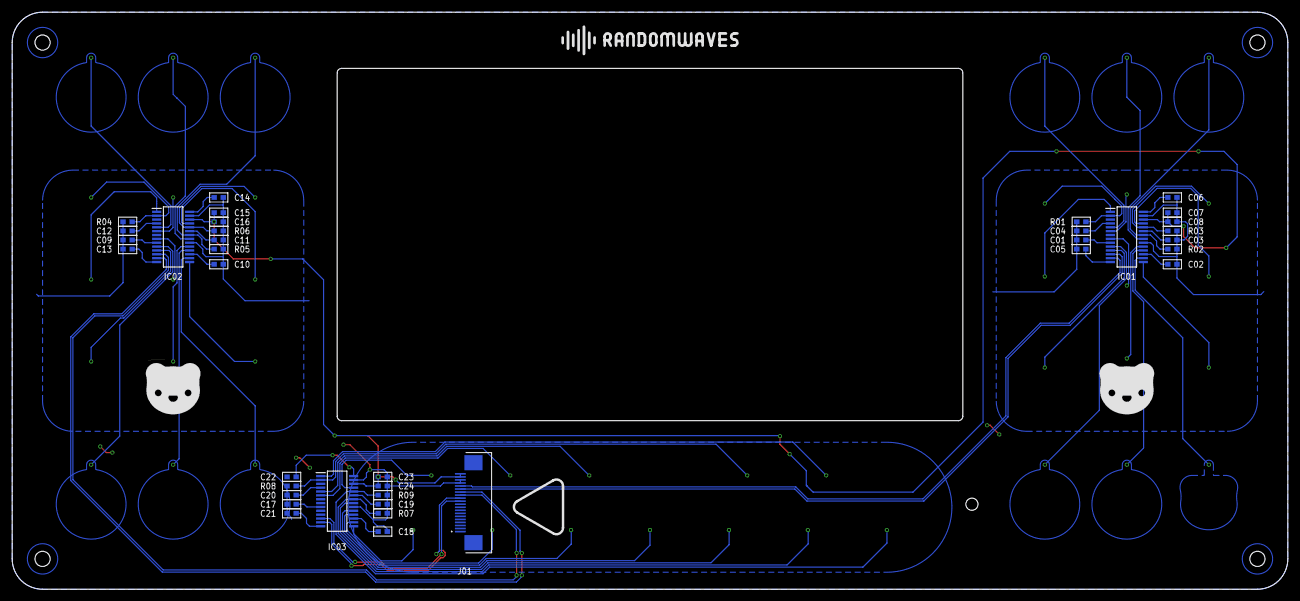
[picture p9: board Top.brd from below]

Board: 2 copper layers, 210.0 x 95.0 mm, 37 parts (37 on the bottom side), 35 nets.

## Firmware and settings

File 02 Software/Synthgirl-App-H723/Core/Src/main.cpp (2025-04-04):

#include "main.h"

#include "Controller.h"
#include "dma.h"
#include "fatfs.h"
#include "fmc.h"
#include "gpio.h"
#include "i2c.h"
#include "i2s.h"
#include "sdmmc.h"
#include "tim.h"
#include "usart.h"

extern "C" void SystemClock_Config();
extern "C" void PeriphCommonClock_Config();
extern "C" void System_Initialize();
extern "C" void Sdram_Initialize();

uint8_t syncInData[2];
uint8_t syncOutData[2];

uint8_t midiRxData;

Controller controller;

int main() {
    HAL_Init();

    SystemClock_Config();
    PeriphCommonClock_Config();

    System_Initialize();
    Sdram_Initialize();

    controller.initialize();

    while (!controller.getPower()) {
        controller.systemUpdate_A();
    }

    controller.systemStart();

    while (controller.getPower()) {
        controller.systemUpdate_B();
    }

    controller.systemReset();
}

extern "C" void SystemClock_Config() {
    RCC_OscInitTypeDef RCC_OscInitStruct = {0};
    RCC_ClkInitTypeDef RCC_ClkInitStruct = {0};

    /** Supply configuration update enable
     */
    HAL_PWREx_ConfigSupply(PWR_LDO_SUPPLY);

    /** Configure the main internal regulator output voltage
     */
    __HAL_PWR_VOLTAGESCALING_CONFIG(PWR_REGULATOR_VOLTAGE_SCALE0);

    while (!__HAL_PWR_GET_FLAG(PWR_FLAG_VOSRDY)) {
    }

    /** Initializes the RCC Oscillators according to the specified parameters
     * in the RCC_OscInitTypeDef structure.
     */
    RCC_OscInitStruct.OscillatorType = RCC_OSCILLATORTYPE_HSE;
    RCC_OscInitStruct.HSEState = RCC_HSE_ON;
    RCC_OscInitStruct.PLL.PLLState = RCC_PLL_ON;
    RCC_OscInitStruct.PLL.PLLSource = RCC_PLLSOURCE_HSE;
    RCC_OscInitStruct.PLL.PLLM = 1;
    RCC_OscInitStruct.PLL.PLLN = 68;
    RCC_OscInitStruct.PLL.PLLP = 1;
    RCC_OscInitStruct.PLL.PLLQ = 3;
    RCC_OscInitStruct.PLL.PLLR = 2;
    RCC_OscInitStruct.PLL.PLLRGE = RCC_PLL1VCIRANGE_3;
    RCC_OscInitStruct.PLL.PLLVCOSEL = RCC_PLL1VCOWIDE;
    RCC_OscInitStruct.PLL.PLLFRACN = 6144;
    if (HAL_RCC_OscConfig(&RCC_OscInitStruct) != HAL_OK) {
        Error_Handler();
    }

    /** Initializes the CPU, AHB and APB buses clocks
     */
    RCC_ClkInitStruct.ClockType = RCC_CLOCKTYPE_HCLK | RCC_CLOCKTYPE_SYSCLK |
                                  RCC_CLOCKTYPE_PCLK1 | RCC_CLOCKTYPE_PCLK2 |
                                  RCC_CLOCKTYPE_D3PCLK1 | RCC_CLOCKTYPE_D1PCLK1;
    RCC_ClkInitStruct.SYSCLKSource = RCC_SYSCLKSOURCE_PLLCLK;
    RCC_ClkInitStruct.SYSCLKDivider = RCC_SYSCLK_DIV1;
    RCC_ClkInitStruct.AHBCLKDivider = RCC_HCLK_DIV2;
    RCC_ClkInitStruct.APB3CLKDivider = RCC_APB3_DIV2;
    RCC_ClkInitStruct.APB1CLKDivider = RCC_APB1_DIV2;
    RCC_ClkInitStruct.APB2CLKDivider = RCC_APB2_DIV2;
    RCC_ClkInitStruct.APB4CLKDivider = RCC_APB4_DIV2;

    if (HAL_RCC_ClockConfig(&RCC_ClkInitStruct, FLASH_LATENCY_3) != HAL_OK) {
        Error_Handler();
    }

    /** Enables the Clock Security System
     */
    HAL_RCC_EnableCSS();
}

extern "C" void PeriphCommonClock_Config() {
    RCC_PeriphCLKInitTypeDef PeriphClkInitStruct = {0};

    /** Initializes the peripherals clock
     */
    PeriphClkInitStruct.PeriphClockSelection =
        RCC_PERIPHCLK_FMC | RCC_PERIPHCLK_SDMMC | RCC_PERIPHCLK_SPI3;
    PeriphClkInitStruct.PLL2.PLL2M = 1;
    PeriphClkInitStruct.PLL2.PLL2N = 30;
    PeriphClkInitStruct.PLL2.PLL2P = 1;
    PeriphClkInitStruct.PLL2.PLL2Q = 2;
    PeriphClkInitStruct.PLL2.PLL2R = 1;
    PeriphClkInitStruct.PLL2.PLL2RGE = RCC_PLL2VCIRANGE_3;
    PeriphClkInitStruct.PLL2.PLL2VCOSEL = RCC_PLL2VCOWIDE;
    PeriphClkInitStruct.PLL2.PLL2FRACN = 0;
    PeriphClkInitStruct.FmcClockSelection = RCC_FMCCLKSOURCE_PLL2;
    PeriphClkInitStruct.SdmmcClockSelection = RCC_SDMMCCLKSOURCE_PLL2;
    PeriphClkInitStruct.Spi123ClockSelection = RCC_SPI123CLKSOURCE_PLL2;
    if (HAL_RCCEx_PeriphCLKConfig(&PeriphClkInitStruct) != HAL_OK) {
        Error_Handler();
    }
}

extern "C" void System_Initialize() {
    MX_GPIO_Init();
    MX_DMA_Init();
    MX_FMC_Init();
    MX_FATFS_Init();
    MX_I2C3_Init();
    MX_I2S3_Init();
    MX_SDMMC2_SD_Init();
    MX_UART4_Init();
    MX_UART7_Init();
    MX_USART1_UART_Init();
    MX_USART6_UART_Init();
    MX_TIM5_Init();
    MX_TIM6_Init();
    MX_TIM7_Init();
    MX_TIM8_Init();
    MX_TIM12_Init();
    MX_TIM13_Init();
    MX_TIM14_Init();
    MX_TIM15_Init();
    MX_TIM16_Init();
    MX_TIM17_Init();
    MX_TIM23_Init();
    MX_TIM24_Init();
}

extern "C" void Sdram_Initialize() {
    SDRAM_HandleTypeDef *hsdram = &hsdram1;
    FMC_SDRAM_CommandTypeDef *Command;

    __IO uint32_t tmpmrd = 0;
    /* Step 3:  Configure a clock configuration enable command */
    Command->CommandMode = FMC_SDRAM_CMD_CLK_ENABLE;
    Command->CommandTarget = FMC_SDRAM_CMD_TARGET_BANK1;
    Command->AutoRefreshNumber = 1;
    Command->ModeRegisterDefinition = 0;

    /* Send the command */
    HAL_SDRAM_SendCommand(hsdram, Command, SDRAM_TIMEOUT);

    /* Step 4: Insert 100 us minimum delay */
    /* Inserted delay is equal to 1 ms due to systick time base unit (ms) */
    HAL_Delay(1);

    /* Step 5: Configure a PALL (precharge all) command */
    Command->CommandMode = FMC_SDRAM_CMD_PALL;
    Command->CommandTarget = FMC_SDRAM_CMD_TARGET_BANK1;
    Command->AutoRefreshNumber = 1;
    Command->ModeRegisterDefinition = 0;

    /* Send the command */
    HAL_SDRAM_SendCommand(hsdram, Command, SDRAM_TIMEOUT);

    /* Step 6 : Configure a Auto-Refresh command */
    Command->CommandMode = FMC_SDRAM_CMD_AUTOREFRESH_MODE;
    Command->CommandTarget = FMC_SDRAM_CMD_TARGET_BANK1;
    Command->AutoRefreshNumber = 4;
    Command->ModeRegisterDefinition = 0;

    /* Send the command */
    HAL_SDRAM_SendCommand(hsdram, Command, SDRAM_TIMEOUT);

    /* Step 7: Program the external memory mode register */
    tmpmrd = (uint32_t)SDRAM_MODEREG_BURST_LENGTH_2 |
             SDRAM_MODEREG_BURST_TYPE_SEQUENTIAL | SDRAM_MODEREG_CAS_LATENCY_2 |
             SDRAM_MODEREG_OPERATING_MODE_STANDARD |
             SDRAM_MODEREG_WRITEBURST_MODE_SINGLE;

    Command->CommandMode = FMC_SDRAM_CMD_LOAD_MODE;
    Command->CommandTarget = FMC_SDRAM_CMD_TARGET_BANK1;
    Command->AutoRefreshNumber = 1;
    Command->ModeRegisterDefinition = tmpmrd;

    /* Send the command */
    HAL_SDRAM_SendCommand(hsdram, Command, SDRAM_TIMEOUT);

    /* Step 8: Set the refresh rate counter */
    /* (15.62 us x Freq) - 20 */
    /* Set the device refresh counter */
    HAL_SDRAM_ProgramRefreshRate(hsdram, 1854);
}

void HAL_GPIO_EXTI_Callback(uint16_t GPIO_Pin) {
    // trigger left button
    if ((GPIO_Pin == CT0_SDO_Pin) &&
        (controller.getLeftButtonState() == PASSIVE)) {
        controller.interruptLeftButtonTrigger();
    }
    // trigger right button
    if ((GPIO_Pin == CT1_SDO_Pin) &&
        (controller.getRightButtonState() == PASSIVE)) {
        controller.interruptRightButtonTrigger();
    }
    // trigger beat button
    if ((GPIO_Pin == CT2_SDO_Pin) &&
        (controller.getBeatButtonState() == PASSIVE)) {
        controller.interruptBeatButtonTrigger();
    }
    // trigger sync in
    /*
    if (GPIO_Pin == SYNC_IN_Pin) {
        if ((controller.getMenu() != INIT_MENU) && (controller.getSystem().syncIn))
            HAL_UART_Receive_DMA(&huart7, syncInData, sizeof(syncInData));
    }
    */
    // trigger button
    if (GPIO_Pin == BUTTON_Pin) {
    }
};

void HAL_TIM_PeriodElapsedCallback(TIM_HandleTypeDef *htim) {
    // effect transition timer
    if (htim->Instance == TIM5) {
        controller.interruptTransition();
    }
    // left button
    if ((htim->Instance == TIM6) &&
        ((controller.getLeftButtonState() != PASSIVE))) {
        controller.interruptLeftButtonRead();
    }
    // right button
    if ((htim->Instance == TIM7) &&
        ((controller.getRightButtonState() != PASSIVE))) {
        controller.interruptRightButtonRead();
    }
    // beat button
    if ((htim->Instance == TIM8) &&
        ((controller.getBeatButtonState() != PASSIVE))) {
        controller.interruptBeatButtonRead();
    }
    // updown button
    if (htim->Instance == TIM12) {
        controller.interruptUpDownButtonRead();
    }
    // long button
    if (htim->Instance == TIM13) {
        controller.interruptLongButtonRead();
    }
    // play
    if (htim->Instance == TIM14) {
        controller.interruptPlay();
    }
    // text
    if (htim->Instance == TIM15) {
        controller.interruptText();
    }
    // power button
    if (htim->Instance == TIM16) {
        controller.interruptPowerButtonRead();
    }
    // sd check
    if (htim->Instance == TIM17) {
        controller.interruptSd();
    }
    // beat sync timer
    if (htim->Instance == TIM23) {
        controller.interruptBeatSync();
    }
    // limit alert timer
    if (htim->Instance == TIM24) {
        controller.interruptLimitAlert();
    }
};

void HAL_TIM_ErrorCallback(TIM_HandleTypeDef *htim) {}

void HAL_I2S_TxCpltCallback(I2S_HandleTypeDef *hi2s) {
    if (hi2s == &hi2s3) {
        controller.interruptAudioSend();
        controller.interruptAudioMetronome();
        controller.interruptAudioSong();
        controller.interruptAudioLpf();
        controller.interruptAudioEq();
        controller.interruptAudioFilter();
        controller.interruptAudioEffect();
        controller.interruptAudioReverb();
    }
}

void HAL_I2S_RxCpltCallback(I2S_HandleTypeDef *hi2s) {}

void HAL_I2S_ErrorCallback(I2S_HandleTypeDef *hi2s) {}

void HAL_UART_TxCpltCallback(UART_HandleTypeDef *huart) {
    if (huart == &huart4) {
    }

    if (huart == &huart6) {
        controller.midiTxBusy = false;
    }
}

void HAL_UART_RxCpltCallback(UART_HandleTypeDef *huart) {
    if (huart == &huart7) {
        controller.receiveSyncCommand();
        HAL_UART_Receive_DMA(&huart7, syncInData, sizeof(syncInData));
    }

    if (huart == &huart1) {
        controller.receiveMidiCommand();
        HAL_UART_Receive_DMA(&huart1, &midiRxData, 1);
    }
}

void HAL_UART_ErrorCallback(UART_HandleTypeDef *huart) {
    if (huart == &huart7) {
        HAL_UART_Receive_DMA(&huart7, syncInData, sizeof(syncInData));
    }

    if (huart == &huart1) {
        HAL_UART_Receive_DMA(&huart1, &midiRxData, 1);
    }
}

void Error_Handler(void) {
    __disable_irq();
    while (1) {
    }
}

#ifdef USE_FULL_ASSERT

void assert_failed(uint8_t *file, uint32_t line) {}

#endif

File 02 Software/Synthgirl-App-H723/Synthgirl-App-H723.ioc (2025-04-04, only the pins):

Mcu.UserName=STM32H723ZGTx
PA0.GPIO_Label=CT0_SCL
PA0.Signal=GPIO_Output
PA1.GPIO_Label=CT0_SDO
PA1.Signal=GPXTI1
PA10.GPIO_Label=SYNC_OUT
PA10.Signal=GPIO_Output
PA11.GPIO_Label=SYNC_OUT_RX
PA11.Signal=GPIO_Output
PA12.GPIO_Label=SYNC_OUT_TX
PA12.Signal=UART4_TX
PA13(JTMS/SWDIO).Signal=DEBUG_JTMS-SWDIO
PA14(JTCK/SWCLK).Signal=DEBUG_JTCK-SWCLK
PA2.GPIO_Label=CT1_SCL
PA2.Signal=GPIO_Output
PA3.GPIO_Label=CT1_SDO
PA3.Signal=GPXTI3
PA4.Signal=I2S3_WS
PA7.GPIO_Label=CT2_SDO
PA7.Signal=GPXTI7
PA8.Signal=I2C3_SCL
PA9.GPIO_Label=MIDI_RX
PA9.Signal=USART1_TX
PB0.GPIO_Label=LCD_D0
PB0.Signal=GPIO_Output
PB1.GPIO_Label=LCD_D1
PB1.Signal=GPIO_Output
PB10.GPIO_Label=LCD_D10
PB10.Signal=GPIO_Output
PB11.GPIO_Label=LCD_D11
PB11.Signal=GPIO_Output
PB12.GPIO_Label=LCD_D12
PB12.Signal=GPIO_Output
PB13.GPIO_Label=LCD_D13
PB13.Signal=GPIO_Output
PB14.GPIO_Label=LCD_D14
PB14.Signal=GPIO_Output
PB15.GPIO_Label=LCD_D15
PB15.Signal=GPIO_Output
PB2.GPIO_Label=LCD_D2
PB2.Signal=GPIO_Output
PB3(JTDO/TRACESWO).GPIO_Label=LCD_D3
PB3(JTDO/TRACESWO).Signal=GPIO_Output
PB4(NJTRST).GPIO_Label=LCD_D4
PB4(NJTRST).Signal=GPIO_Output
PB5.GPIO_Label=LCD_D5
PB5.Signal=GPIO_Output
PB6.GPIO_Label=LCD_D6
PB6.Signal=GPIO_Output
PB7.GPIO_Label=LCD_D7
PB7.Signal=GPIO_Output
PB8.GPIO_Label=LCD_D8
PB8.Signal=GPIO_Output
PB9.GPIO_Label=LCD_D9
PB9.Signal=GPIO_Output
PC0.Signal=FMC_SDNWE
PC10.Signal=I2S3_CK
PC12.Signal=I2S3_SDO
PC13.GPIO_Label=SDMMC2_DETECT
PC13.Signal=GPIO_Input
PC4.Signal=FMC_SDNE0
PC5.Signal=FMC_SDCKE0
PC6.GPIO_Label=MIDI_TX
PC6.Signal=USART6_TX
PC7.Signal=I2S3_MCK
PC9.Signal=I2C3_SDA
PD0.Signal=FMC_D2_DA2
PD1.Signal=FMC_D3_DA3
PD10.Signal=FMC_D15_DA15
PD11.GPIO_Label=LED0
PD11.Signal=GPIO_Output
PD12.GPIO_Label=LED1
PD12.Signal=GPIO_Output
PD13.GPIO_Label=LED2
PD13.Signal=GPIO_Output
PD14.Signal=FMC_D0_DA0
PD15.Signal=FMC_D1_DA1
PD2.GPIO_Label=LCD_CS
PD2.Signal=GPIO_Output
PD3.GPIO_Label=LCD_RD
PD3.Signal=GPIO_Output
PD4.GPIO_Label=LCD_WR
PD4.Signal=GPIO_Output
PD5.GPIO_Label=LCD_RS
PD5.Signal=GPIO_Output
PD6.Signal=SDMMC2_CK
PD7.Signal=SDMMC2_CMD
PD8.Signal=FMC_D13_DA13
PD9.Signal=FMC_D14_DA14
PE0.Signal=FMC_NBL0
PE1.Signal=FMC_NBL1
PE10.Signal=FMC_D7_DA7
PE11.Signal=FMC_D8_DA8
PE12.Signal=FMC_D9_DA9
PE13.Signal=FMC_D10_DA10
PE14.Signal=FMC_D11_DA11
PE15.Signal=FMC_D12_DA12
PE2.GPIO_Label=CT2_SCL
PE2.Signal=GPIO_Output
PE7.Signal=FMC_D4_DA4
PE8.Signal=FMC_D5_DA5
PE9.Signal=FMC_D6_DA6
PF0.Signal=FMC_A0
PF1.Signal=FMC_A1
PF10.GPIO_Label=BUTTON
PF10.Signal=GPXTI10
PF11.Signal=FMC_SDNRAS
PF12.Signal=FMC_A6
PF13.Signal=FMC_A7
PF14.Signal=FMC_A8
PF15.Signal=FMC_A9
PF2.Signal=FMC_A2
PF3.Signal=FMC_A3
PF4.Signal=FMC_A4
PF5.Signal=FMC_A5
PF6.GPIO_Label=SYNC_IN_RX
PF6.Signal=UART7_RX
PF7.GPIO_Label=SYNC_IN_TX
PF7.Signal=UART7_TX
PF8.GPIO_Label=SYNC_IN
PF8.Signal=GPXTI8
PG0.Signal=FMC_A10
PG1.Signal=FMC_A11
PG10.Signal=SDMMC2_D1
PG11.Signal=SDMMC2_D2
PG12.Signal=SDMMC2_D3
PG13.GPIO_Label=LCD_RESET
PG13.Signal=GPIO_Output
PG14.GPIO_Label=LCD_BL
PG14.Signal=GPIO_Output
PG15.Signal=FMC_SDNCAS
PG4.Signal=FMC_A14_BA0
PG5.Signal=FMC_A15_BA1
PG8.Signal=FMC_SDCLK
PG9.Signal=SDMMC2_D0
PH0-OSC_IN.Signal=RCC_OSC_IN
PH1-OSC_OUT.Signal=RCC_OSC_OUT

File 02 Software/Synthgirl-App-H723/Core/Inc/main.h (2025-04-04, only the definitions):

#define CT2_SCL_Pin GPIO_PIN_2
#define CT2_SCL_GPIO_Port GPIOE
#define SDMMC2_DETECT_Pin GPIO_PIN_13
#define SDMMC2_DETECT_GPIO_Port GPIOC
#define SYNC_IN_RX_Pin GPIO_PIN_6
#define SYNC_IN_RX_GPIO_Port GPIOF
#define SYNC_IN_TX_Pin GPIO_PIN_7
#define SYNC_IN_TX_GPIO_Port GPIOF
#define SYNC_IN_Pin GPIO_PIN_8
#define SYNC_IN_GPIO_Port GPIOF
#define SYNC_IN_EXTI_IRQn EXTI9_5_IRQn
#define BUTTON_Pin GPIO_PIN_10
#define BUTTON_GPIO_Port GPIOF
#define BUTTON_EXTI_IRQn EXTI15_10_IRQn
#define CT0_SCL_Pin GPIO_PIN_0
#define CT0_SCL_GPIO_Port GPIOA
#define CT0_SDO_Pin GPIO_PIN_1
#define CT0_SDO_GPIO_Port GPIOA
#define CT0_SDO_EXTI_IRQn EXTI1_IRQn
#define CT1_SCL_Pin GPIO_PIN_2
#define CT1_SCL_GPIO_Port GPIOA
#define CT1_SDO_Pin GPIO_PIN_3
#define CT1_SDO_GPIO_Port GPIOA
#define CT1_SDO_EXTI_IRQn EXTI3_IRQn
#define CT2_SDO_Pin GPIO_PIN_7
#define CT2_SDO_GPIO_Port GPIOA
#define CT2_SDO_EXTI_IRQn EXTI9_5_IRQn
#define LCD_D0_Pin GPIO_PIN_0
#define LCD_D0_GPIO_Port GPIOB
#define LCD_D1_Pin GPIO_PIN_1
#define LCD_D1_GPIO_Port GPIOB
#define LCD_D2_Pin GPIO_PIN_2
#define LCD_D2_GPIO_Port GPIOB
#define LCD_D10_Pin GPIO_PIN_10
#define LCD_D10_GPIO_Port GPIOB
#define LCD_D11_Pin GPIO_PIN_11
#define LCD_D11_GPIO_Port GPIOB
#define LCD_D12_Pin GPIO_PIN_12
#define LCD_D12_GPIO_Port GPIOB
#define LCD_D13_Pin GPIO_PIN_13
#define LCD_D13_GPIO_Port GPIOB
#define LCD_D14_Pin GPIO_PIN_14
#define LCD_D14_GPIO_Port GPIOB
#define LCD_D15_Pin GPIO_PIN_15
#define LCD_D15_GPIO_Port GPIOB
#define LED0_Pin GPIO_PIN_11
#define LED0_GPIO_Port GPIOD
#define LED1_Pin GPIO_PIN_12
#define LED1_GPIO_Port GPIOD
#define LED2_Pin GPIO_PIN_13
#define LED2_GPIO_Port GPIOD
#define MIDI_TX_Pin GPIO_PIN_6
#define MIDI_TX_GPIO_Port GPIOC
#define MIDI_RX_Pin GPIO_PIN_9
#define MIDI_RX_GPIO_Port GPIOA
#define SYNC_OUT_Pin GPIO_PIN_10
#define SYNC_OUT_GPIO_Port GPIOA
#define SYNC_OUT_RX_Pin GPIO_PIN_11
#define SYNC_OUT_RX_GPIO_Port GPIOA
#define SYNC_OUT_TX_Pin GPIO_PIN_12
#define SYNC_OUT_TX_GPIO_Port GPIOA
#define LCD_CS_Pin GPIO_PIN_2
#define LCD_CS_GPIO_Port GPIOD
#define LCD_RD_Pin GPIO_PIN_3
#define LCD_RD_GPIO_Port GPIOD
#define LCD_WR_Pin GPIO_PIN_4
#define LCD_WR_GPIO_Port GPIOD
#define LCD_RS_Pin GPIO_PIN_5
#define LCD_RS_GPIO_Port GPIOD
#define LCD_RESET_Pin GPIO_PIN_13
#define LCD_RESET_GPIO_Port GPIOG
#define LCD_BL_Pin GPIO_PIN_14
#define LCD_BL_GPIO_Port GPIOG
#define LCD_D3_Pin GPIO_PIN_3
#define LCD_D3_GPIO_Port GPIOB
#define LCD_D4_Pin GPIO_PIN_4
#define LCD_D4_GPIO_Port GPIOB
#define LCD_D5_Pin GPIO_PIN_5
#define LCD_D5_GPIO_Port GPIOB
#define LCD_D6_Pin GPIO_PIN_6
#define LCD_D6_GPIO_Port GPIOB
#define LCD_D7_Pin GPIO_PIN_7
#define LCD_D7_GPIO_Port GPIOB
#define LCD_D8_Pin GPIO_PIN_8
#define LCD_D8_GPIO_Port GPIOB
#define LCD_D9_Pin GPIO_PIN_9
#define LCD_D9_GPIO_Port GPIOB

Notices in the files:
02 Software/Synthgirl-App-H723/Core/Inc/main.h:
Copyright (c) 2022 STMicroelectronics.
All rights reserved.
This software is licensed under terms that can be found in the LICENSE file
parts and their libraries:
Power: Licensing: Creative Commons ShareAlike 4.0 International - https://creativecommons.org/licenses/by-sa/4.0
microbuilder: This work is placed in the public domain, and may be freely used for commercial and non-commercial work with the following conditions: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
